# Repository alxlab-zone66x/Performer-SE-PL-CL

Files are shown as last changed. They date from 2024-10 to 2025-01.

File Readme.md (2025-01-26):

# Micromac Performer SE/Plus/Classic Clone

This is a recreation of the MicroMac SE/Plus/Classic accelerator.  
The schematics have been reverse engineered and a new PCB was created based on the schematics.

fully populated board

The provided PCB files are licensed under CC-BY-NC-SA - they are NOT intended for commercial use.  

## Notes on GALs and jumpers

The original GALs have been dumped. GAL16V8-15 as well as PALCE16V8-15 have been tested as suitable replacement.
Faster/slower chips as well as ATF16V8 of any speed haven't been tested so far.

U3, U4, U5 and U6 are mandatory. U7 is only needed for operation in Macintosh Plus and Classic.
Close SJ2 if U7 isn't installed. SJ2 HAS to be open when U7 is installed.

Close SJ1 to run the optional 68882 off the 16MHz accelerator clock.
Install an oscillator and open SJ1 to run the 68882 at any speed.
The original design used 25MHz which has been verified to work on the clone as well.

I have not found a socket that allows secure installation over the PLCC CPU in the Macintosh Classic.
Proper operation has been tested in the Macintosh Plus and SE but so far not on the Classic.

## Board Files

The provided gerber files have been generated using the JLCPCB EAGLE cam job files.  

The Kicad project files are placed inside the `kicad` folder. It's been slightly tweaked from the original Eagle project to pass DRC. The silkscreen for the Macintosh Classic and Macintosh Plus were moved to the bottom.

| Board Revision | Description | |
| :--- | --- | --- |
| Performer PL-CL-SE | Original recreation by Bolle. | [gerbers and bom](production/Performer_PL-CL-SE.zip) |
| Performer SE v1.0 socket pga  | SE only, 2 layers, PGA FPU, PGA CPU, PLCC-20 through-hole sockets | [gerbers and assembly](production/Performer-SE_v1.0_socket-pga.zip) |
| Performer SE v1.1 socket pga  | SE only, 2 layers, PGA FPU, PGA CPU, PLCC-20 through-hole sockets | [gerbers and assembly](production/Performer-SE_v1.1_socket-pga.zip) |
| Performer SE v1.0 socket plcc | SE only, 2 layers, PLCC FPU, PGA CPU, PLCC-20 through-hole sockets | [gerbers and assembly](production/Performer-SE_v1.0_socket-plcc.zip) |
| Performer SE v1.1 socket plcc | SE only, 2 layers, PLCC FPU, PGA CPU, PLCC-20 through-hole sockets | [gerbers and assembly](production/Performer-SE_v1.1_socket-plcc.zip) |

## Bill of Materials

### Performer SE

Parts shared between the Performer SE design variations.

| Quantity | Description | Designators | Product Number |
| :--- | --- | --- | --- |
| 4 | 100uF 6.3v 1206 mlcc | C1, C2, C3, C4 | |
| 5 | 0.1uF 6.3v 1206 mlcc | C5, C6, C7, C8, C9 | |
| 18 | 4.7kOhms 1/4W 1206 resistor | R1, R2, R3, R4, R5, R6, R7, R8, R9, R10, R11, R12, R13, R14, R15, R16, R17, R18 | |
| 4-6 | 0.5mm press-fit pin socket (optional) | QG1 | [0531-0-15-15-31-27-10-0](docs/datasheets/Mill-Max_0531-0-15-15-31-27-10-0.pdf) |
| 1 | 25MHz oscillator 8-pin or 14-pin dip (optional) | QG1 | [ECS-2200B-250](docs/datasheets/ECS_ECS-2200B-250.pdf), [ECS-100AX-250](docs/datasheets/ECS_ECS-100AX-250.pdf) |
| 1 | pga-128 through-hole socket (optional) | U1 | |
| 4 | plcc-20 through-hole socket | U3, U4, U5, U6 | [PLCC-20-AT](docs/datasheets/Adam-Tech_PLCC-20-AT.pdf) |

### Performer SE - PLCC FPU

| Quantity | Description | Designators | Product Number |
| :--- | --- | --- | --- |
| 1 | plcc-68 through-hole socket | U2 | [PLCC-68-AT](docs/datasheets/Adam-Tech_PLCC-68-AT.pdf) |

### Performer SE - PGA FPU

| Quantity | Description | Designators | Product Number |
| :--- | --- | --- | --- |
| 1 | pga-68 through-hole socket (optional) | U2 | |

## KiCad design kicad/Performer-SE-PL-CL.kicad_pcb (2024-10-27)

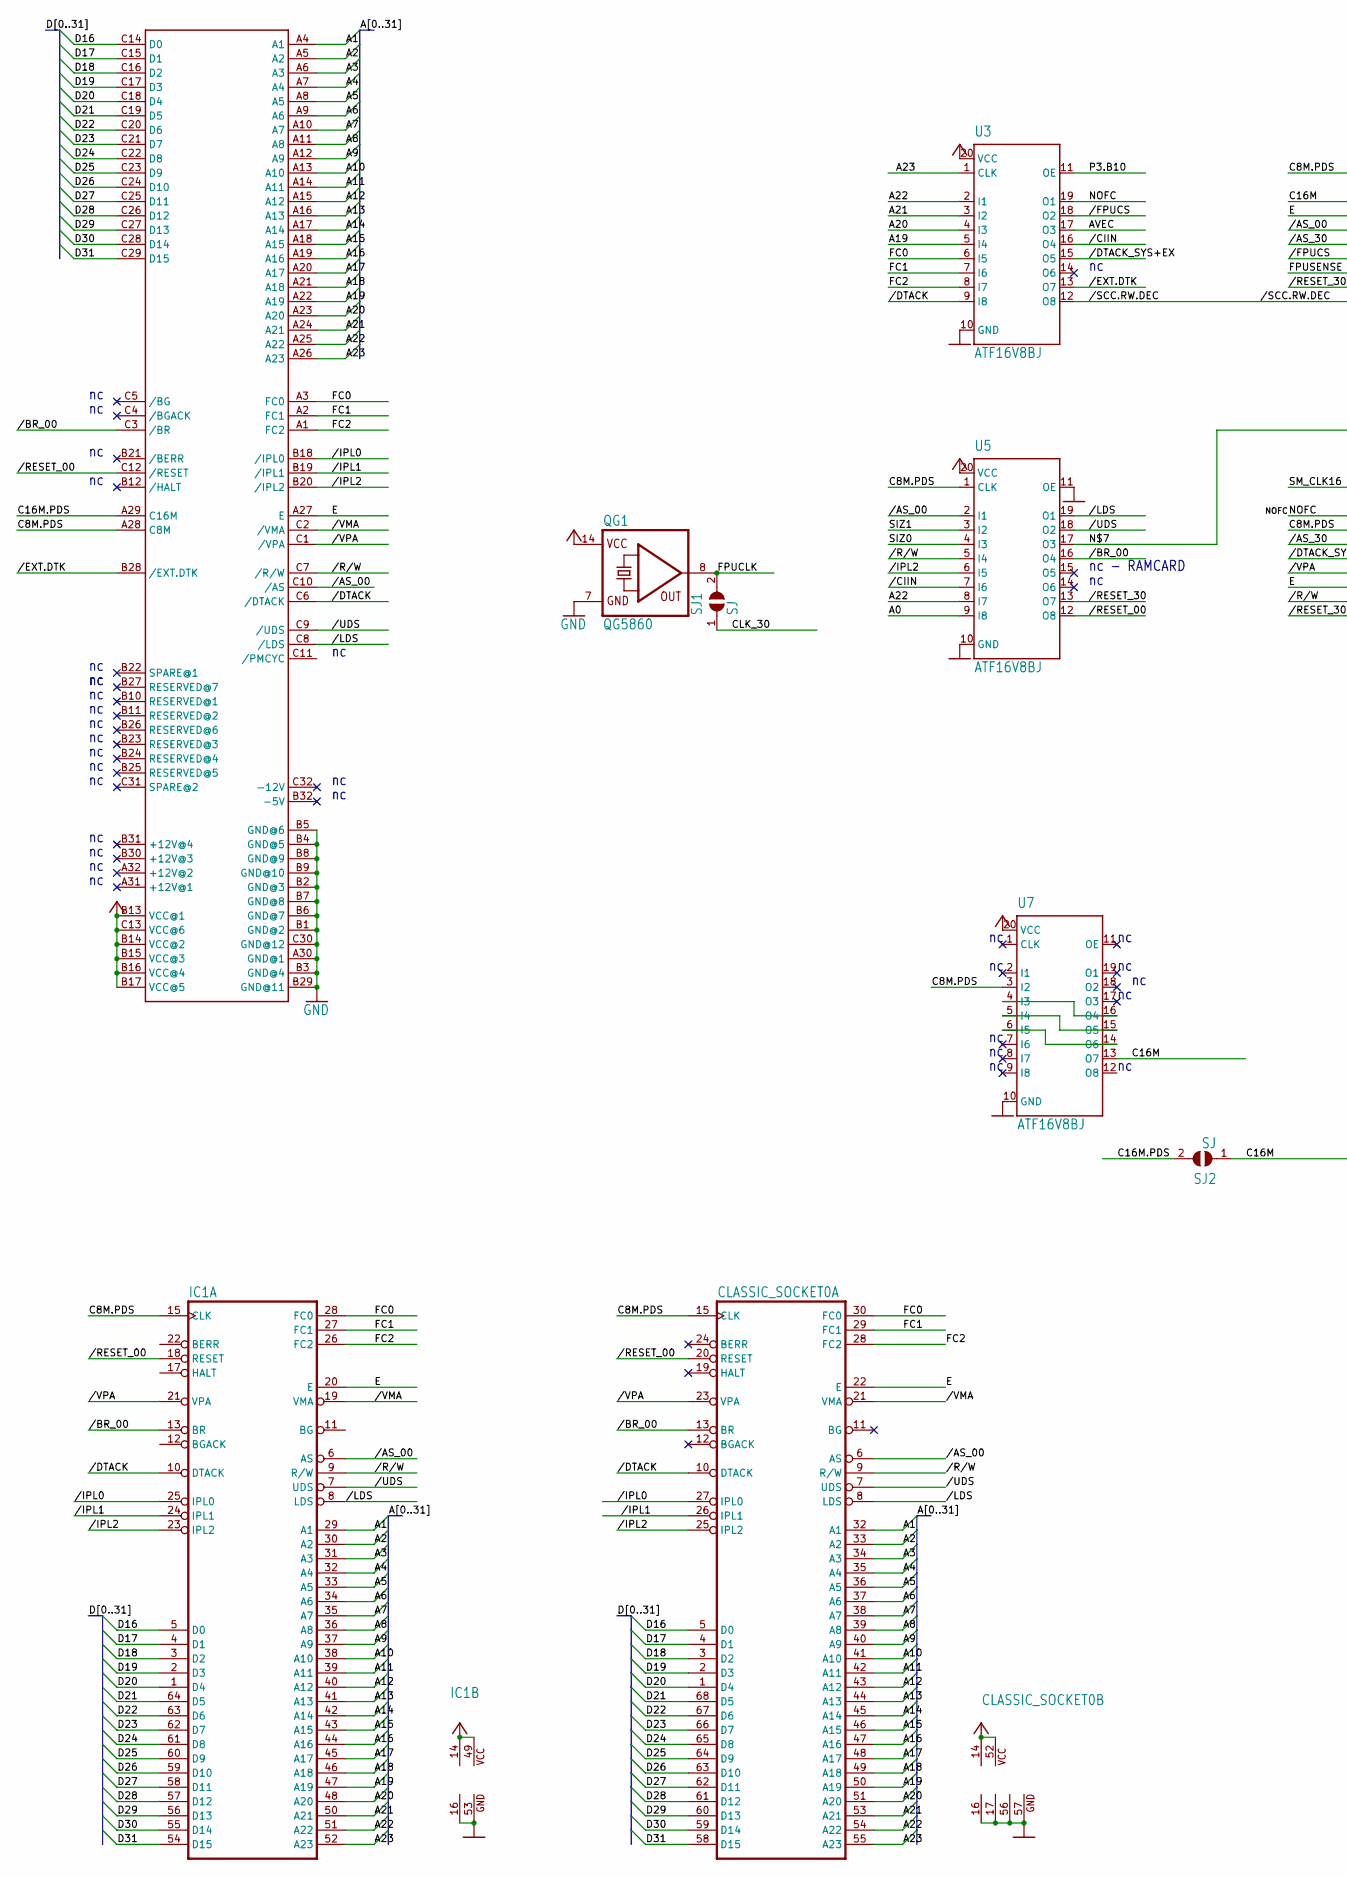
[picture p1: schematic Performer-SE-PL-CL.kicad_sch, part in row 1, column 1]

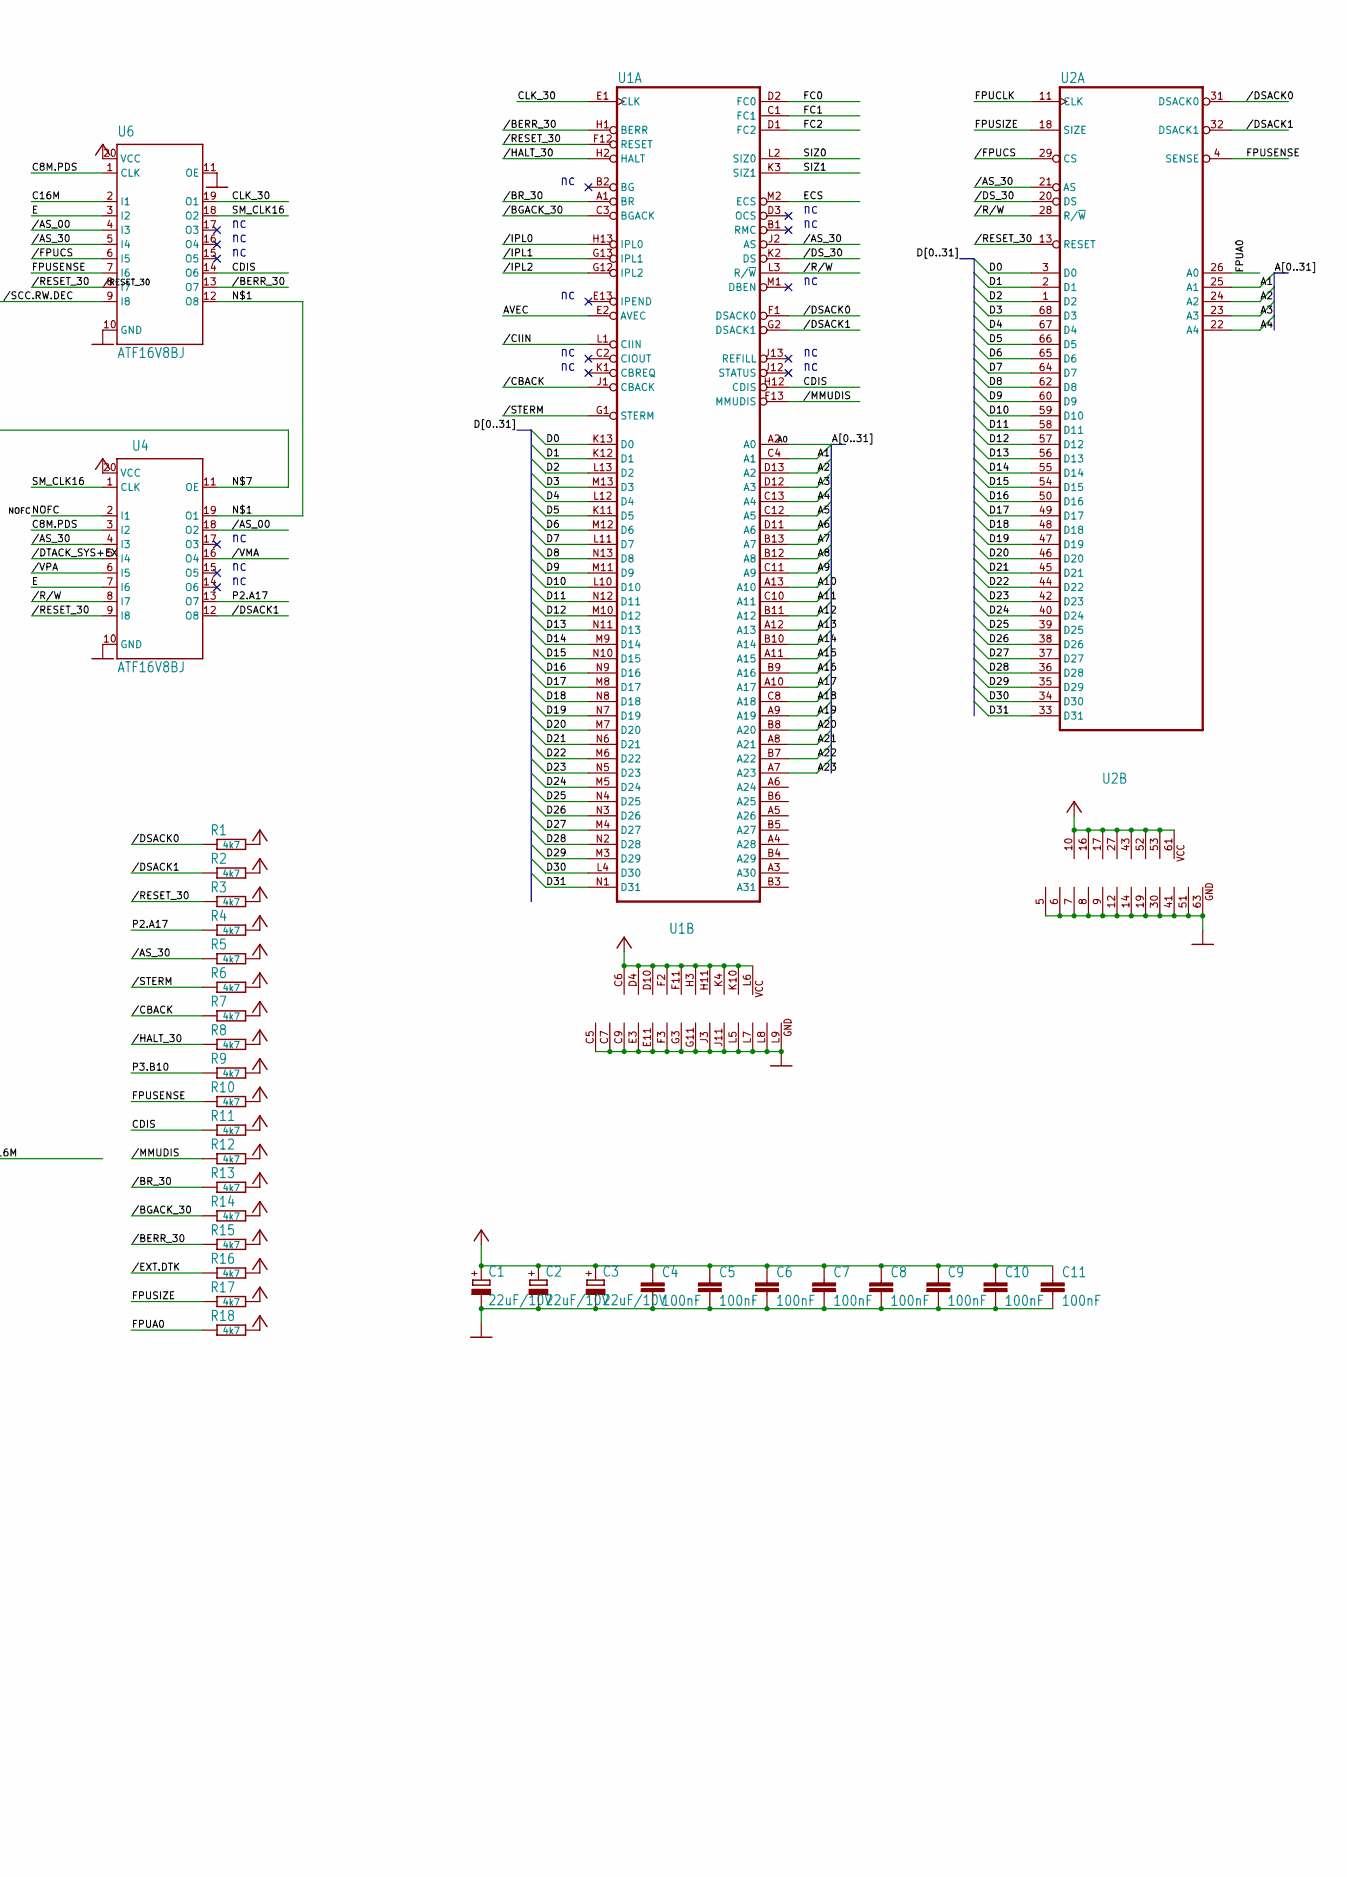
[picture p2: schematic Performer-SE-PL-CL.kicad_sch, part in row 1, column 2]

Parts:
C1, C2, C3: 22uF/10V; CP_EIA-6032-15_Kemet-U_Pad2.25x2.35mm_HandSolder
C4, C5, C6, C7, C8, C9, C10, C11: 100nF; C_1206_3216Metric_Pad1.60x1.80mm_HandSolder
CLASSIC_SOCKET0: MC68000FN-SOC; PLCC-68_THT-Socket_Mirror
IC1: MC68000P; DIP-64_W22.86mm_LongPads_Mirror
J1: MAC_SE_PDS; DIN41612_R_3x32_Male_Vertical_THT_Mirror_NoMountingHoles
QG1: QG5860; Oscillator_DIP-14
R1, R2, R3, R4, R5, R6, R7, R8, R9, R10, R11, R12, R13, R14, R15, R16, R17, R18: 4k7; R_1206_3216Metric_Pad1.60x1.80mm_HandSolder
SJ1, SJ2: SJ; SolderJumper-2_P1.3mm_Open_TrianglePad1.0x1.5mm
U1: MC68030RC; CPGA-128_Layout13x13_MC68030
U2: MC68881FN-SOC; PLCC-68_THT-Socket
U3, U4, U5, U6, U7: ATF16V8BJ; PLCC-20

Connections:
/A0: U1.A2 (A0), U5.9 (I8)
/A1: CLASSIC_SOCKET0.32 (A1), IC1.29 (A1), J1.A4 (A1), U1.C4 (A1), U2.25 (A1)
/A2: CLASSIC_SOCKET0.33 (A2), IC1.30 (A2), J1.A5 (A2), U1.D13 (A2), U2.24 (A2)
/A3: CLASSIC_SOCKET0.34 (A3), IC1.31 (A3), J1.A6 (A3), U1.D12 (A3), U2.23 (A3)
/A4: CLASSIC_SOCKET0.35 (A4), IC1.32 (A4), J1.A7 (A4), U1.C13 (A4), U2.22 (A4)
/A5: CLASSIC_SOCKET0.36 (A5), IC1.33 (A5), J1.A8 (A5), U1.C12 (A5)
/A6: CLASSIC_SOCKET0.37 (A6), IC1.34 (A6), J1.A9 (A6), U1.D11 (A6)
/A7: CLASSIC_SOCKET0.38 (A7), IC1.35 (A7), J1.A10 (A7), U1.B13 (A7)
/A8: CLASSIC_SOCKET0.39 (A8), IC1.36 (A8), J1.A11 (A8), U1.B12 (A8)
/A9: CLASSIC_SOCKET0.40 (A9), IC1.37 (A9), J1.A12 (A9), U1.C11 (A9)
/A10: CLASSIC_SOCKET0.41 (A10), IC1.38 (A10), J1.A13 (A10), U1.A13 (A10)
/A11: CLASSIC_SOCKET0.42 (A11), IC1.39 (A11), J1.A14 (A11), U1.C10 (A11)
/A12: CLASSIC_SOCKET0.43 (A12), IC1.40 (A12), J1.A15 (A12), U1.B11 (A12)
/A13: CLASSIC_SOCKET0.44 (A13), IC1.41 (A13), J1.A16 (A13), U1.A12 (A13)
/A14: CLASSIC_SOCKET0.45 (A14), IC1.42 (A14), J1.A17 (A14), U1.B10 (A14)
/A15: CLASSIC_SOCKET0.46 (A15), IC1.43 (A15), J1.A18 (A15), U1.A11 (A15)
/A16: CLASSIC_SOCKET0.47 (A16), IC1.44 (A16), J1.A19 (A16), U1.B9 (A16)
/A17: CLASSIC_SOCKET0.48 (A17), IC1.45 (A17), J1.A20 (A17), U1.A10 (A17)
/A18: CLASSIC_SOCKET0.49 (A18), IC1.46 (A18), J1.A21 (A18), U1.C8 (A18)
/A19: CLASSIC_SOCKET0.50 (A19), IC1.47 (A19), J1.A22 (A19), U1.A9 (A19), U3.5 (I4)
/A20: CLASSIC_SOCKET0.51 (A20), IC1.48 (A20), J1.A23 (A20), U1.B8 (A20), U3.4 (I3)
/A21: CLASSIC_SOCKET0.53 (A21), IC1.50 (A21), J1.A24 (A21), U1.A8 (A21), U3.3 (I2)
/A22: CLASSIC_SOCKET0.54 (A22), IC1.51 (A22), J1.A25 (A22), U1.B7 (A22), U3.2 (I1), U5.8 (I7)
/A23: CLASSIC_SOCKET0.55 (A23), IC1.52 (A23), J1.A26 (A23), U1.A7 (A23), U3.1 (CLK)
/AVEC: U1.E2 (AVEC), U3.17 (O3)
/C8M.PDS: CLASSIC_SOCKET0.15 (CLK), IC1.15 (CLK), J1.A28 (C8M), U4.3 (I2), U5.1 (CLK), U6.1 (CLK), U7.3 (I2)
/C16M: SJ2.1, U6.2 (I1), U7.13 (O7)
/C16M.PDS: J1.A29 (C16M), SJ2.2
/CDIS: R11.1, U1.H12 (CDIS), U6.14 (O6)
/CLK_30: SJ1.1, U1.E1 (CLK), U6.19 (O1)
/D0: U1.K13 (D0), U2.3 (D0)
/D1: U1.K12 (D1), U2.2 (D1)
/D2: U1.L13 (D2), U2.1 (D2)
/D3: U1.M13 (D3), U2.68 (D3)
/D4: U1.L12 (D4), U2.67 (D4)
/D5: U1.K11 (D5), U2.66 (D5)
/D6: U1.M12 (D6), U2.65 (D6)
/D7: U1.L11 (D7), U2.64 (D7)
/D8: U1.N13 (D8), U2.62 (D8)
/D9: U1.M11 (D9), U2.60 (D9)
/D10: U1.L10 (D10), U2.59 (D10)
/D11: U1.N12 (D11), U2.58 (D11)
/D12: U1.M10 (D12), U2.57 (D12)
/D13: U1.N11 (D13), U2.56 (D13)
/D14: U1.M9 (D14), U2.55 (D14)
/D15: U1.N10 (D15), U2.54 (D15)
/D16: CLASSIC_SOCKET0.5 (D0), IC1.5 (D0), J1.C14 (D0), U1.N9 (D16), U2.50 (D16)
/D17: CLASSIC_SOCKET0.4 (D1), IC1.4 (D1), J1.C15 (D1), U1.M8 (D17), U2.49 (D17)
/D18: CLASSIC_SOCKET0.3 (D2), IC1.3 (D2), J1.C16 (D2), U1.N8 (D18), U2.48 (D18)
/D19: CLASSIC_SOCKET0.2 (D3), IC1.2 (D3), J1.C17 (D3), U1.N7 (D19), U2.47 (D19)
/D20: CLASSIC_SOCKET0.1 (D4), IC1.1 (D4), J1.C18 (D4), U1.M7 (D20), U2.46 (D20)
/D21: CLASSIC_SOCKET0.68 (D5), IC1.64 (D5), J1.C19 (D5), U1.N6 (D21), U2.45 (D21)
/D22: CLASSIC_SOCKET0.67 (D6), IC1.63 (D6), J1.C20 (D6), U1.M6 (D22), U2.44 (D22)
/D23: CLASSIC_SOCKET0.66 (D7), IC1.62 (D7), J1.C21 (D7), U1.N5 (D23), U2.42 (D23)
/D24: CLASSIC_SOCKET0.65 (D8), IC1.61 (D8), J1.C22 (D8), U1.M5 (D24), U2.40 (D24)
/D25: CLASSIC_SOCKET0.64 (D9), IC1.60 (D9), J1.C23 (D9), U1.N4 (D25), U2.39 (D25)
/D26: CLASSIC_SOCKET0.63 (D10), IC1.59 (D10), J1.C24 (D10), U1.N3 (D26), U2.38 (D26)
/D27: CLASSIC_SOCKET0.62 (D11), IC1.58 (D11), J1.C25 (D11), U1.M4 (D27), U2.37 (D27)
/D28: CLASSIC_SOCKET0.61 (D12), IC1.57 (D12), J1.C26 (D12), U1.N2 (D28), U2.36 (D28)
/D29: CLASSIC_SOCKET0.60 (D13), IC1.56 (D13), J1.C27 (D13), U1.M3 (D29), U2.35 (D29)
/D30: CLASSIC_SOCKET0.59 (D14), IC1.55 (D14), J1.C28 (D14), U1.L4 (D30), U2.34 (D30)
/D31: CLASSIC_SOCKET0.58 (D15), IC1.54 (D15), J1.C29 (D15), U1.N1 (D31), U2.33 (D31)
/E: CLASSIC_SOCKET0.22 (E), IC1.20 (E), J1.A27 (E), U4.7 (I6), U6.3 (I2)
/ECS: U1.M2 (ECS)
/FC0: CLASSIC_SOCKET0.30 (FC0), IC1.28 (FC0), J1.A3 (FC0), U1.D2 (FC0), U3.6 (I5)
/FC1: CLASSIC_SOCKET0.29 (FC1), IC1.27 (FC1), J1.A2 (FC1), U1.C1 (FC1), U3.7 (I6)
/FC2: CLASSIC_SOCKET0.28 (FC2), IC1.26 (FC2), J1.A1 (FC2), U1.D1 (FC2), U3.8 (I7)
/FPUA0: R18.1, U2.26 (A0)
/FPUCLK: QG1.8 (OUT), SJ1.2, U2.11 (CLK)
/FPUSENSE: R10.1, U2.4 (SENSE), U6.7 (I6)
/FPUSIZE: R17.1, U2.18 (SIZE)
/N$1: U4.19 (O1), U6.12 (O8)
/N$7: U4.11 (OE), U5.17 (O3)
/NOFC: U3.19 (O1), U4.2 (I1)
/P2.A17: R4.1, U4.13 (O7)
/P3.B10: R9.1, U3.11 (OE)
/SIZ0: U1.L2 (SIZ0), U5.4 (I3)
/SIZ1: U1.K3 (SIZ1), U5.3 (I2)
/SM_CLK16: U4.1 (CLK), U6.18 (O2)
//AS_00: CLASSIC_SOCKET0.6 (AS), IC1.6 (AS), J1.C10 (/AS), U4.18 (O2), U5.2 (I1), U6.4 (I3)
//AS_30: R5.1, U1.J2 (AS), U2.21 (AS), U4.4 (I3), U6.5 (I4)
//BERR_30: R15.1, U1.H1 (BERR), U6.13 (O7)
//BGACK_30: R14.1, U1.C3 (BGACK)
//BR_00: CLASSIC_SOCKET0.13 (BR), IC1.13 (BR), J1.C3 (/BR), U5.16 (O4)
//BR_30: R13.1, U1.A1 (BR)
//CBACK: R7.1, U1.J1 (CBACK)
//CIIN: U1.L1 (CIIN), U3.16 (O4), U5.7 (I6)
//DSACK0: R1.1, U1.F1 (DSACK0), U2.31 (DSACK0)
//DSACK1: R2.1, U1.G2 (DSACK1), U2.32 (DSACK1), U4.12 (O8)
//DS_30: U1.K2 (DS), U2.20 (DS)
//DTACK: CLASSIC_SOCKET0.10 (DTACK), IC1.10 (DTACK), J1.C6 (/DTACK), U3.9 (I8)
//DTACK_SYS+EX: U3.15 (O5), U4.5 (I4)
//EXT.DTK: J1.B28 (/EXT.DTK), R16.1, U3.13 (O7)
//FPUCS: U2.29 (CS), U3.18 (O2), U6.6 (I5)
//HALT_30: R8.1, U1.H2 (HALT)
//IPL0: CLASSIC_SOCKET0.27 (IPL0), IC1.25 (IPL0), J1.B18 (/IPL0), U1.H13 (IPL0)
//IPL1: CLASSIC_SOCKET0.26 (IPL1), IC1.24 (IPL1), J1.B19 (/IPL1), U1.G13 (IPL1)
//IPL2: CLASSIC_SOCKET0.25 (IPL2), IC1.23 (IPL2), J1.B20 (/IPL2), U1.G12 (IPL2), U5.6 (I5)
//LDS: CLASSIC_SOCKET0.8 (LDS), IC1.8 (LDS), J1.C8 (/LDS), U5.19 (O1)
//MMUDIS: R12.1, U1.F13 (MMUDIS)
//RESET_00: CLASSIC_SOCKET0.20 (RESET), IC1.18 (RESET), J1.C12 (/RESET), U5.12 (O8)
//RESET_30: R3.1, U1.F12 (RESET), U2.13 (RESET), U4.9 (I8), U5.13 (O7), U6.8 (I7)
//R/W: CLASSIC_SOCKET0.9 (R/W), IC1.9 (R/W), J1.C7 (/R/W), U1.L3 (R/~W), U2.28 (R/~W), U4.8 (I7), U5.5 (I4)
//SCC.RW.DEC: U3.12 (O8), U6.9 (I8)
//STERM: R6.1, U1.G1 (STERM)
//UDS: CLASSIC_SOCKET0.7 (UDS), IC1.7 (UDS), J1.C9 (/UDS), U5.18 (O2)
//VMA: CLASSIC_SOCKET0.21 (VMA), IC1.19 (VMA), J1.C2 (/VMA), U4.16 (O4)
//VPA: CLASSIC_SOCKET0.23 (VPA), IC1.21 (VPA), J1.C1 (/VPA), U4.6 (I5)
GND: C1.-, C2.-, C3.-, C4.2, C5.2, C6.2, C7.2, C8.2, C9.2, C10.2, C11.2, CLASSIC_SOCKET0.16 (GND@1), CLASSIC_SOCKET0.17 (GND@2), CLASSIC_SOCKET0.56 (GND@3), CLASSIC_SOCKET0.57 (GND@4), IC1.16 (GND@1), IC1.53 (GND@2), J1.A30 (GND@1), J1.B1 (GND@2), J1.B2 (GND@3), J1.B3 (GND@4), J1.B4 (GND@5), J1.B5 (GND@6), J1.B6 (GND@7), J1.B7 (GND@8), J1.B8 (GND@9), J1.B9 (GND@10), J1.B29 (GND@11), J1.C30 (GND@12), QG1.7 (GND), U1.C5 (GND@1), U1.C7 (GND@2), U1.C9 (GND@3), U1.E3 (GND@4), U1.E11 (GND@5), U1.F3 (GND@6), U1.G3 (GND@7), U1.G11 (GND@8), U1.J3 (GND@9), U1.J11 (GND@10), U1.L5 (GND@11), U1.L7 (GND@12), U1.L8 (GND@13), U1.L9 (GND@14), U2.5 (GND@1), U2.6 (GND@2), U2.7 (GND@3), U2.8 (GND@4), U2.9 (GND@5), U2.12 (GND@6), U2.14 (GND@7), U2.19 (GND@8), U2.30 (GND@9), U2.41 (GND@10), U2.51 (GND@11), U2.63 (GND@12), U3.10 (GND), U4.10 (GND), U5.10 (GND), U5.11 (OE), U6.10 (GND), U6.11 (OE), U7.10 (GND)
unnamed: U7.4 (I3), U7.16 (O4)
unnamed: U7.5 (I4), U7.15 (O5)
unnamed: U7.6 (I5), U7.14 (O6)
VCC: C1.+, C2.+, C3.+, C4.1, C5.1, C6.1, C7.1, C8.1, C9.1, C10.1, C11.1, CLASSIC_SOCKET0.14 (VCC@1), CLASSIC_SOCKET0.52 (VCC@2), IC1.14 (VCC@1), IC1.49 (VCC@2), J1.B13 (VCC@1), J1.B14 (VCC@2), J1.B15 (VCC@3), J1.B16 (VCC@4), J1.B17 (VCC@5), J1.C13 (VCC@6), QG1.14 (VCC), R1.2, R2.2, R3.2, R4.2, R5.2, R6.2, R7.2, R8.2, R9.2, R10.2, R11.2, R12.2, R13.2, R14.2, R15.2, R16.2, R17.2, R18.2, U1.C6 (VCC@1), U1.D4 (VCC@2), U1.D10 (VCC@3), U1.F2 (VCC@4), U1.F11 (VCC@5), U1.H3 (VCC@6), U1.H11 (VCC@7), U1.K4 (VCC@8), U1.K10 (VCC@9), U1.L6 (VCC@10), U2.10 (VCC@1), U2.16 (VCC@2), U2.17 (VCC@3), U2.27 (VCC@4), U2.43 (VCC@5), U2.52 (VCC@6), U2.53 (VCC@7), U2.61 (VCC@8), U3.20 (VCC), U4.20 (VCC), U5.20 (VCC), U6.20 (VCC), U7.20 (VCC)

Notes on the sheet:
nc - RAMCARD

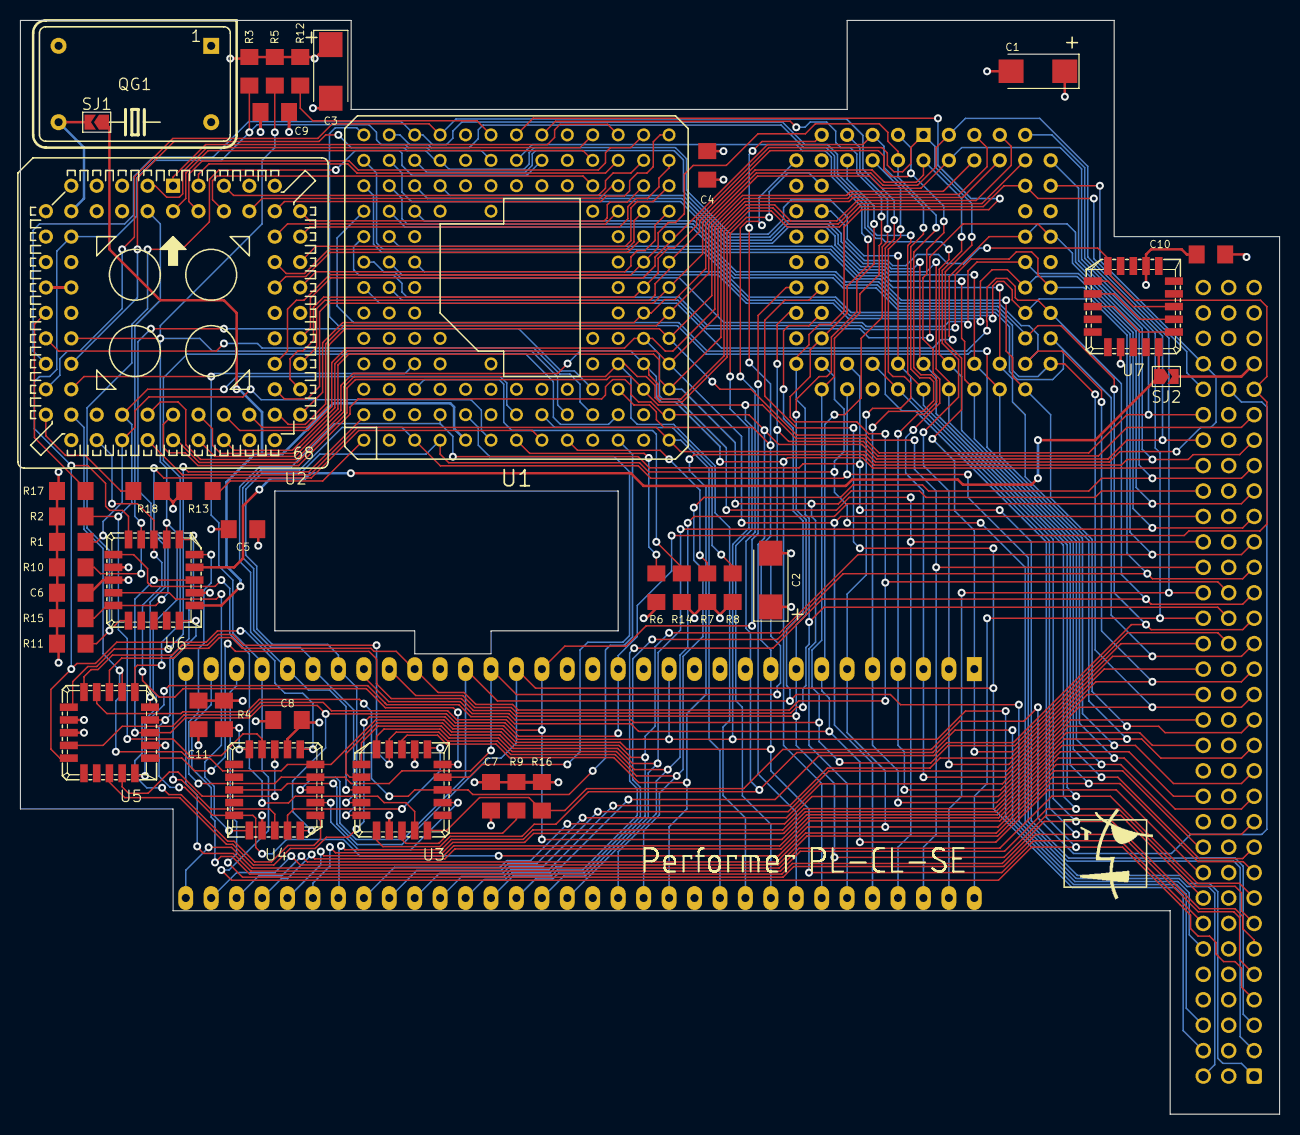
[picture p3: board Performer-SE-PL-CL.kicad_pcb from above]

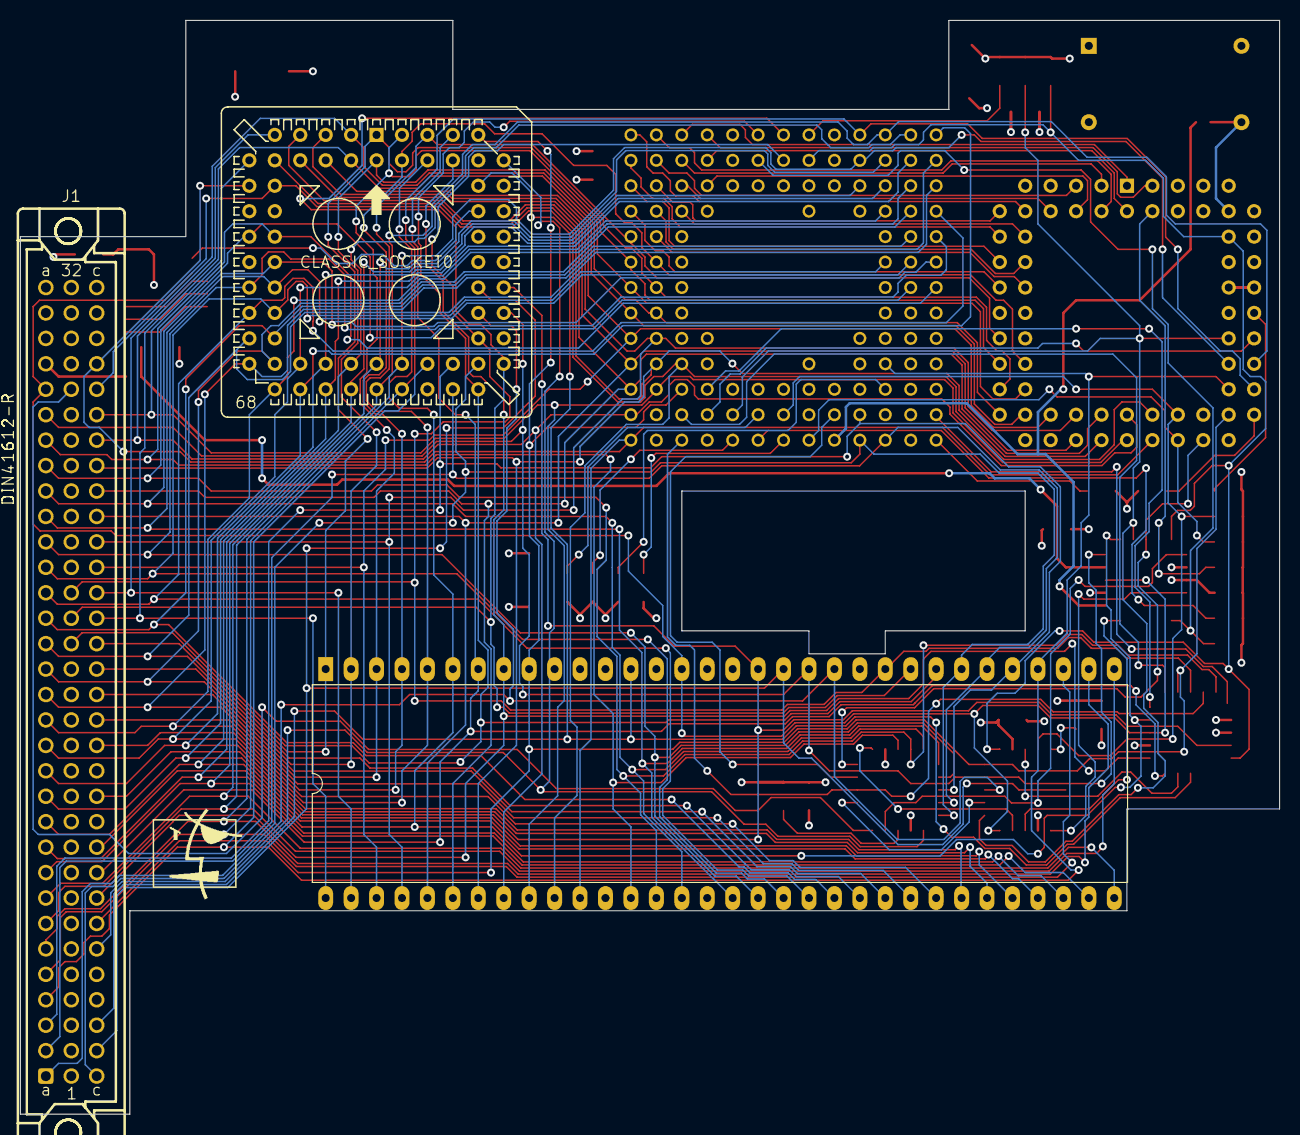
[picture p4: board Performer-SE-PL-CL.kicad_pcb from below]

Board: 4 copper layers, 125.7 x 109.2 mm, 42 parts (3 on the bottom side), 112 nets.

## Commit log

2024-10-14 Add Kicad project files
    [Performer-SE-PL-CL.kicad_pcb, Performer-SE-PL-CL.kicad_sch]
2024-10-14 Rename MC68030 Kicad footprint
    [Performer-SE-PL-CL.kicad_pcb, Performer-SE-PL-CL.kicad_sch]
2024-10-14 Update the MC68030 footprint
    [Performer-SE-PL-CL.kicad_pcb, Performer-SE-PL-CL.kicad_sch]
2024-10-27 Update and add footprints/symbols
2024-10-27 Update PDS footprint of the Performer-SE-PL-CL
    [Performer-SE-PL-CL.kicad_pcb, Performer-SE-PL-CL.kicad_sch]
2024-10-27 Remove extra silkscreens from Performer-SE-PL-CL
    [Performer-SE-PL-CL.kicad_pcb]
2024-11-24 Add Performer SE revision
    [Performer-SE_v1.0_socket-pga.kicad_sch, Performer-SE_v1.0_socket-plcc.kicad_sch, Performer-SE_v1.1_socket-pga.kicad_sch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]
